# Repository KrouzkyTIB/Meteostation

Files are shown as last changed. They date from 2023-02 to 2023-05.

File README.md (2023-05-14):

# Meteostanice

Toto je projekt kroužku bastlení s rodiči z letního pololetí roku 2023. 

## Módy
Meteostanice je možné používat ve dvou módech. Podle toho zdali je připojena v lokální síti či nikoliv. Módy se liší pouze v tom, že pokud máte stanici připojenou k Wi-Fi, tak je možné se na ní připojit pomocí Vašeho telefonu či jiného zařízení a nechat si zobrazit teplotu a vlhkost ve webové stránce. V obou případech funguje display stejně, takže pokud se nechcete koukat přes webový prohlížeč na naměřené teploty, tak není potřeba si s tímto krokem lámat hlavu.
### Stanice není připojená k Wi-Fi
Stanici v tomto módu čeká, až se bude moci připojit na lokální Wi-Fi. Pro to aby to mohla udělat je nutné, jí předat ssid (jméno) a heslo k Vaší domácí Wi-Fi. Pro tento účel meteostanice vytvoří přístupový bod jehož jméno se objeví na horním řádku displaye.
Po připojení na přístupový bod je potřeba zadat do prohlížeče kam zadáváte doménu zadat IP adresu napsanou na displayi na druhém řádku. V tomto případě je IP adresa nastavena na 192.168.0.10. Po zadání adresy do prohlížeče by se Vám měla zobrazit webová stránka na které je možné vyplnit jméno a heslo lokální Wi-Fi sítě.
Do webové stránky zadejte Vaše přístupové údaje a potvrďte, poté začne blikat LED dioda na stanici označující, že se stanice snaží připojit na lokální síť. Poté až blikání ustane tak je Vaše stanice úspěšně připojena k lokální síti. 
Pokud blikání do cca půl minuty nepřestane tak je velice pravděpodobné, že jste udělali někde chybu při zadávání přihlašovacích údajů do stanice a stanice se nemůže připojit. Pokud se Vám toto stane tak je potřeba kkliknout na tlačítko RST_WIFI, ktera vymaže Wi-Fi nastavení a následně je potřeba restartovat zařízení pomocí tlačítka RST nebo zapnutím a vypnutím. Tím uvedete stanici do továrního nastavení a můžete to zkusit znovu.
Po zadání přihlašovacích údajů k Wi-Fi síti si je meteostanice sama uloží do paměti a bude se poté vždy automaticky připojovat.
### Stanice je připojena k Wi-Fi
V tomto módu máte Vaši stanici připojenou k Wi-Fi síti. Meteostanice Vám po svém zapnutí na display vypíše, že je připojena a napíše Vám IP adresu, kterou dostala přiřazenou od Vaše routeru (přístupového bodu). Tuto adresu je dobré si poznamenat, protože při každém restartu může meteostanice dostat jinou IP adresu pod kterou se na ni můžete připojit.
Po zadání IP adresy zařízení do prohlížeče Vaše telefonu či jiného zařízení se Vám objeví stránka s aktuálními naměřenými hodnotami a s možností vymazat přihlašovací údaje k lokální síti a tím opět uvést zařízení do předchozího módu.

#### Poznámka na závěr
Je důležité brát v potaz to, že se jedná o poměrně slabý čip a může se tak stát to, že bude prodleva načítání stránek trošku delší než jste zvyklí u běžných webových stránek. Ze stejného důvodu je omezen maximální počet připojených zařízení v prvním módu na 1 zařízení.

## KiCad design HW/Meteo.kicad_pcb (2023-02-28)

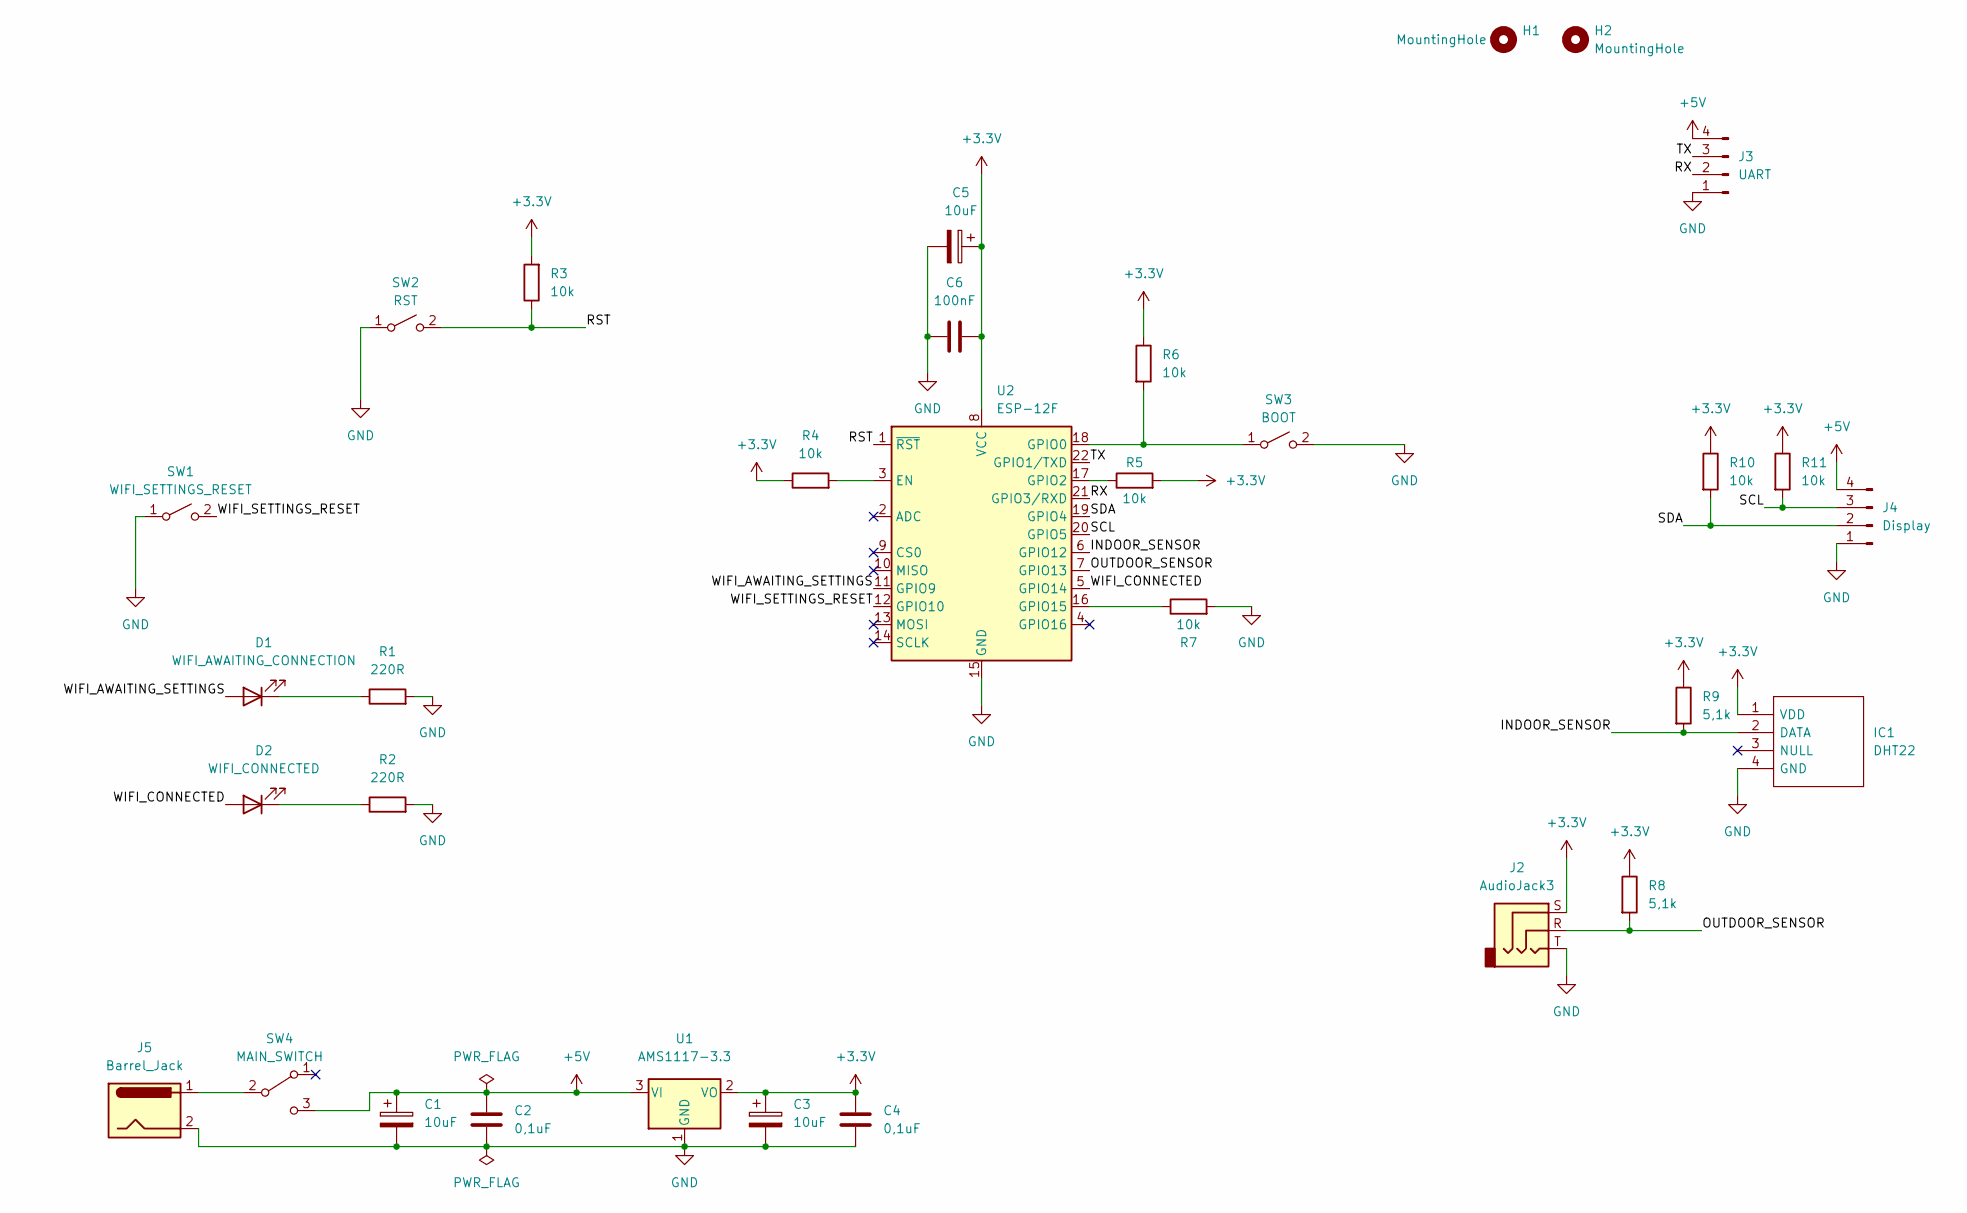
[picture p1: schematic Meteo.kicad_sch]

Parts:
C1, C3, C5: 10uF; CP_Radial_D5.0mm_P2.50mm
C2, C4: 0,1uF; C_Disc_D3.0mm_W1.6mm_P2.50mm
C6: 100nF; C_Disc_D3.0mm_W1.6mm_P2.50mm
D1: WIFI_AWAITING_CONNECTION; LED_D3.0mm
D2: WIFI_CONNECTED; LED_D3.0mm
H1, H2: MountingHole; MountingHole_3.2mm_M3
IC1: DHT22; Manufacturer_Part_Number DHT22
J2: AudioJack3; Jack_3.5mm_CUI_SJ1-3525N_Horizontal
J3: UART; PinHeader_1x04_P2.54mm_Vertical
J4: Display; PinHeader_1x04_P2.54mm_Vertical
J5: Barrel_Jack; BarrelJack_Horizontal
R1, R2: 220R; R_Axial_DIN0207_L6.3mm_D2.5mm_P7.62mm_Horizontal
R3, R4, R5, R6, R7, R10, R11: 10k; R_Axial_DIN0207_L6.3mm_D2.5mm_P7.62mm_Horizontal
R8, R9: 5,1k; R_Axial_DIN0207_L6.3mm_D2.5mm_P7.62mm_Horizontal
SW1: WIFI_SETTINGS_RESET; SW_PUSH_6mm
SW2: RST; SW_PUSH_6mm
SW3: BOOT; SW_PUSH_6mm
SW4: MAIN_SWITCH; SW_CuK_OS102011MA1QN1_SPDT_Angled
U1: AMS1117-3.3; SOT-223-3_TabPin2
U2: ESP-12F; ESP-12E

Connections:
+3.3V: C3.1, C4.1, C5.1, C6.2, IC1.1 (VDD), J2.S, R3.2, R4.1, R5.2, R6.1, R8.1, R9.1, R10.1, R11.1, U1.2 (VO), U2.8 (VCC)
+5V: C1.1, C2.1, J3.4, J4.4, SW4.3 (C), U1.3 (VI)
/INDOOR_SENSOR: IC1.2 (DATA), R9.2, U2.6 (GPIO12)
/OUTDOOR_SENSOR: J2.R, R8.2, U2.7 (GPIO13)
/RST: R3.1, SW2.2 (B), U2.1 (~RST)
/RX: J3.2, U2.21 (GPIO3/RXD)
/SCL: J4.3, R11.2, U2.20 (GPIO5)
/SDA: J4.2, R10.2, U2.19 (GPIO4)
/TX: J3.3, U2.22 (GPIO1/TXD)
/WIFI_AWAITING_SETTINGS: D1.2 (A), U2.11 (GPIO9)
/WIFI_CONNECTED: D2.2 (A), U2.5 (GPIO14)
/WIFI_SETTINGS_RESET: SW1.2 (B), U2.12 (GPIO10)
GND: C1.2, C2.2, C3.2, C4.2, C5.2, C6.1, IC1.4 (GND), J2.T, J3.1, J4.1, J5.2, R1.2, R2.2, R7.2, SW1.1 (A), SW2.1 (A), SW3.2 (B), U1.1 (GND), U2.15 (GND)
unnamed: D1.1 (K), R1.1
unnamed: D2.1 (K), R2.1
unnamed: J5.1, SW4.2 (B)
unnamed: R4.2, U2.3 (EN)
unnamed: R5.1, U2.17 (GPIO2)
unnamed: R6.2, SW3.1 (A), U2.18 (GPIO0)
unnamed: R7.1, U2.16 (GPIO15)

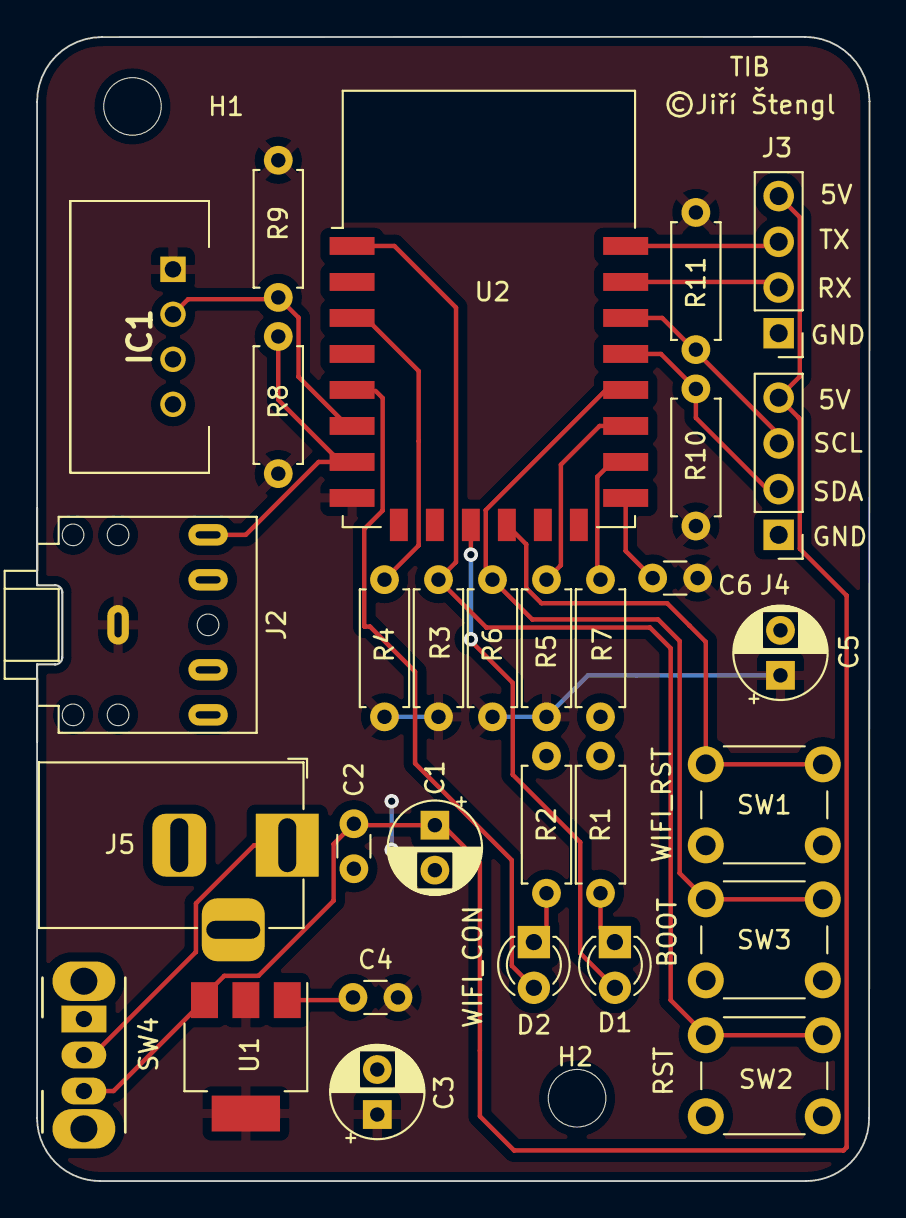
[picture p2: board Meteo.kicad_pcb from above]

Board: 2 copper layers, 46.2 x 63.6 mm, 32 parts (0 on the bottom side), 20 nets.

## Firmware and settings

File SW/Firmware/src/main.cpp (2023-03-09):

#include <Arduino.h>
#include "sensor/Sensor.hpp"
#include "PinDefinitions.hpp"
#include "display/Display.hpp"
#include "filesystem/Filesystem.hpp"
#include "wifi/WifiHandler.hpp"
#include "server/ServerWrapper.hpp"

#define DEBOUNCING_TIME 100

uint64_t buttonClickedTimestamp = 0;


Sensor indoorSensor(INDOOR_SENSOR_PIN);
Sensor outdoorSensor(OUTDOOR_SENSOR_PIN);
Display display(indoorSensor, outdoorSensor);
WifiHandler wifiHandler(display);

void resetWifiButtonHandler();

void setup() {
    pinMode(WIFI_CONNECTED_PIN, OUTPUT);
    pinMode(RESET_WIFI_SETTINGS_PIN, INPUT_PULLUP);
    Serial.begin(115200);
    filesystem::init();
    indoorSensor.init();
    outdoorSensor.init();
    display.init();
    display.turnBacklightOn();
    wifiHandler.init();
    ServerWrapper::init(&wifiHandler, &indoorSensor, &outdoorSensor, &display);
    attachInterrupt(digitalPinToInterrupt(RESET_WIFI_SETTINGS_PIN), resetWifiButtonHandler, FALLING);
}

void loop() {
    display.update();
    ServerWrapper::handleClient();
    if (buttonClickedTimestamp + DEBOUNCING_TIME < millis() || buttonClickedTimestamp > millis()) {
        buttonClickedTimestamp = 0;
    }
}

void ICACHE_RAM_ATTR resetWifiButtonHandler() {
    if (buttonClickedTimestamp == 0) {
        wifiHandler.resetSettings();
        buttonClickedTimestamp = millis();
    }
}

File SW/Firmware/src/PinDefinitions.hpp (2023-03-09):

//
// Created by jiri on 1.3.23.
//

#ifndef FIRMWARE_PINDEFINITIONS_HPP
#define FIRMWARE_PINDEFINITIONS_HPP

#define TEST_LED_PIN 9
#define RESET_WIFI_SETTINGS_PIN 10
#define INDOOR_SENSOR_PIN 12
#define OUTDOOR_SENSOR_PIN 13
#define WIFI_CONNECTED_PIN 14
#endif //FIRMWARE_PINDEFINITIONS_HPP

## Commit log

2023-02-28 Hardware status + gitignore
    [Meteo.kicad_pcb, Meteo.kicad_sch]
2023-03-01 Running indoor temperature sensor
2023-03-01 Working outdoor sensor
2023-03-05 Working reset wifi endpoint
    [WifiHandler.cpp]
2023-03-05 Working reset wifi by button
    [PinDefinitions.hpp, WifiHandler.cpp, main.cpp]

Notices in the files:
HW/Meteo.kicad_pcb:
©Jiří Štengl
